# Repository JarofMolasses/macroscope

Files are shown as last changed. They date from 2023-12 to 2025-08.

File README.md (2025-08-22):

# Macroscope
This is a basic, constant-height, contact mode profilometer/AFM. It's really more of a demonstration piece but ~10 micron resolution can be achieved with some patience.

Inspired by this paper: [*Macro-scale atomic force microscope: An experimental platform for teaching precision mechatronics*](https://www.sciencedirect.com/science/article/abs/pii/S0957415815001488).

# Results
### Canadian nickel scanned at 1.75mm/s, 0.25mm resolution, 88x88 pixels 
A "quick" scan. It took 46 minutes.


### 3D printed test sample with 0.1mm steps. Scanned at 0.5mm/s, 0.05mm resolution, 60x20 pixels
You can see the diagonal print lines on the lowest step.


With a dollar for scale:



# Mechanical
## Initial working prototype 

## Second prototype 


# Control
This machine is programmed using SCPI-ish ASCII commands over a serial port.\
The control GUI we used for the prototype machines can be found here: https://github.com/JarofMolasses/macroscope_control. 

*Created by [David Antoniuk](https://github.com/DavidAntoniuk) and [myself](https://github.com/JarofMolasses).*

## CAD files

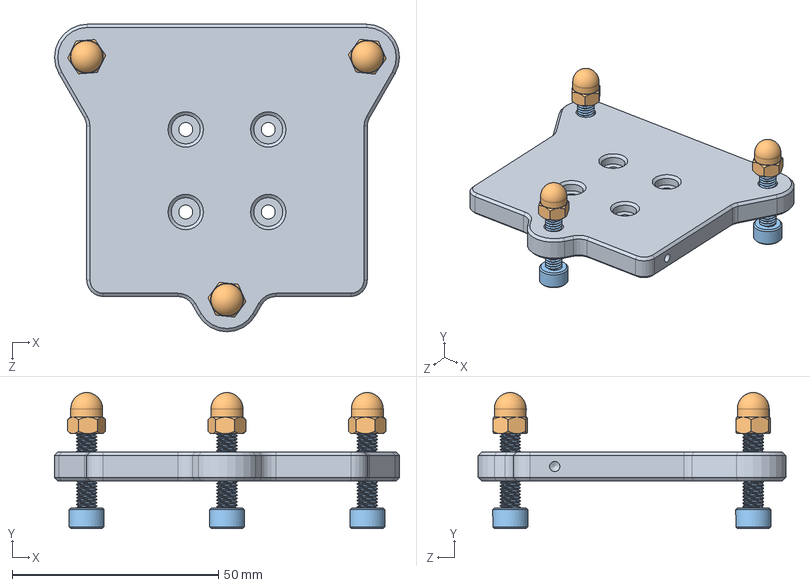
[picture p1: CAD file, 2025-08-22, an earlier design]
CAD archive/Kinematic_Mount_Subassembly.SLDASM
83.6 x 33.0 x 74.5 mm
Kinematic_Mount_Base
M5 94000A037_18-8 Stainless Steel Cap Nut x 3
M5x20 SHCS - 91292A128_18-8 Stainless Steel Socket Head Screw x 3

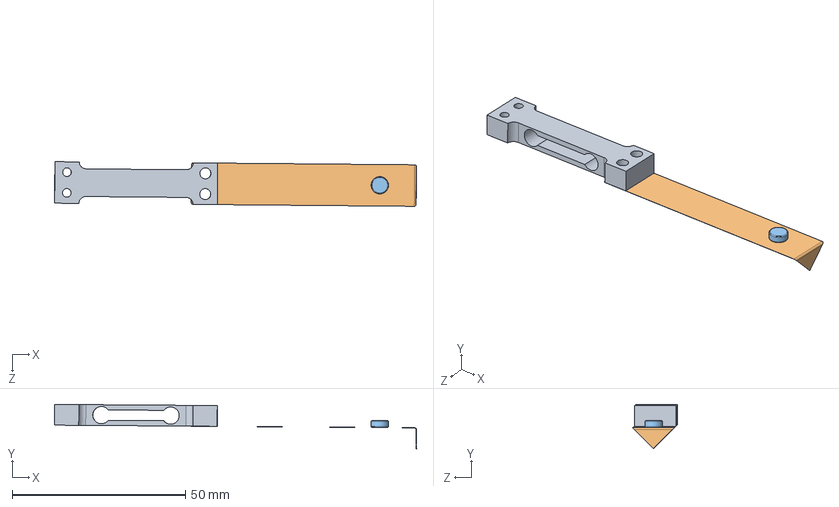
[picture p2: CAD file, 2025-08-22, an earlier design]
CAD archive/Probe_Subassembly.SLDASM
104.6 x 12.8 x 12.9 mm
Load_Cell
Probe
Magnet

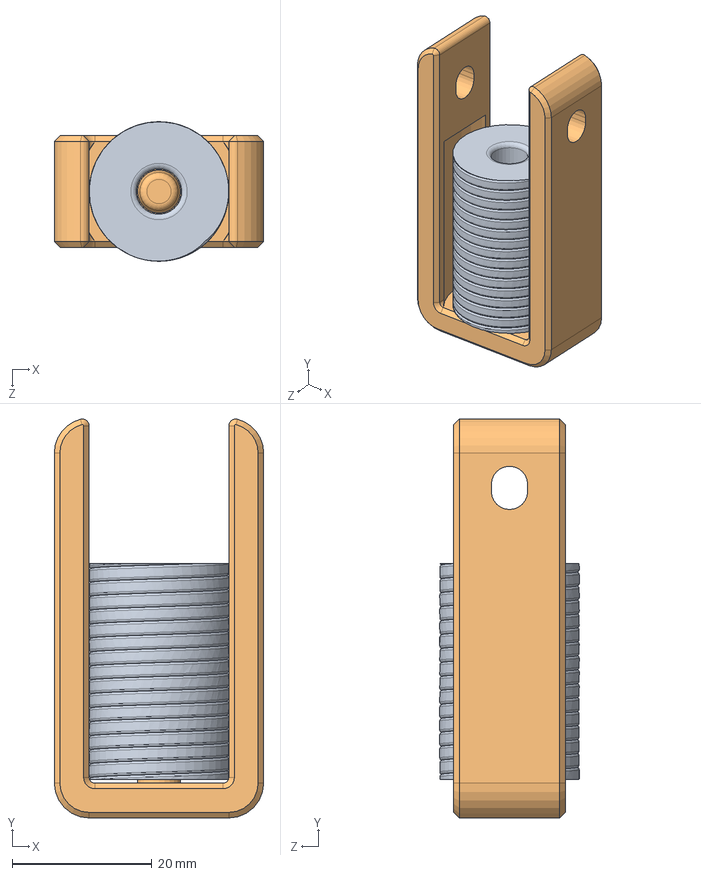
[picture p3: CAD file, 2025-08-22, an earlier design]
CAD archive/Coil_Subassembly.SLDASM
30.0 x 57.2 x 20.0 mm
Coil_Placeholder
Coil_Mount

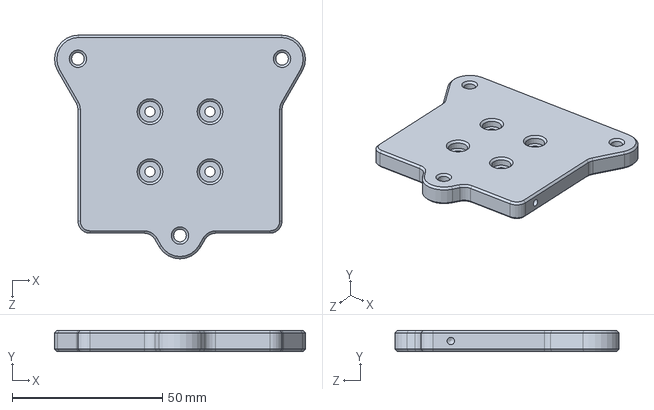
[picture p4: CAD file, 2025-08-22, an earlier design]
CAD archive/Kinematic_Mount_Base.SLDPRT
83.6 x 7.00 x 74.5 mm

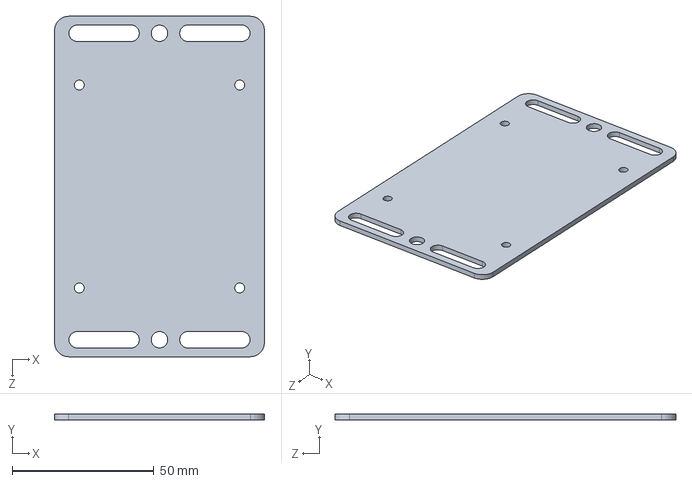
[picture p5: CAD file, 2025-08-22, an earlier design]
CAD archive/ADC backplate.SLDPRT
74.0 x 2.00 x 120.0 mm

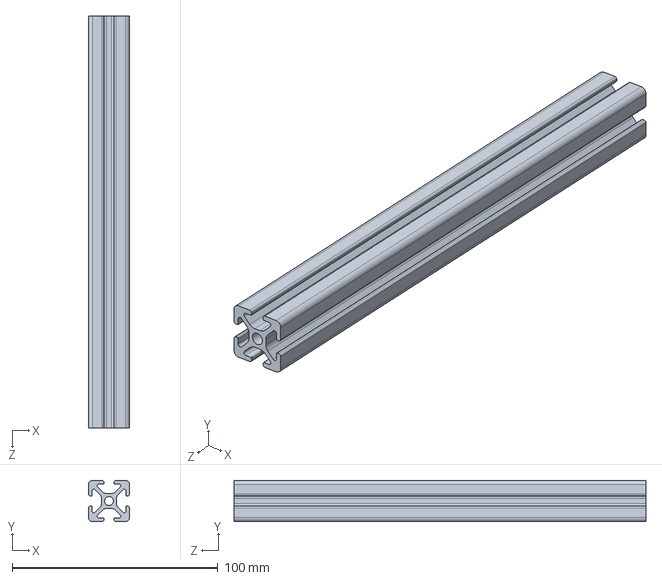
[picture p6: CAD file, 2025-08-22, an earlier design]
CAD archive/Extrusion_2020_200.SLDPRT
20.0 x 20.0 x 200.0 mm

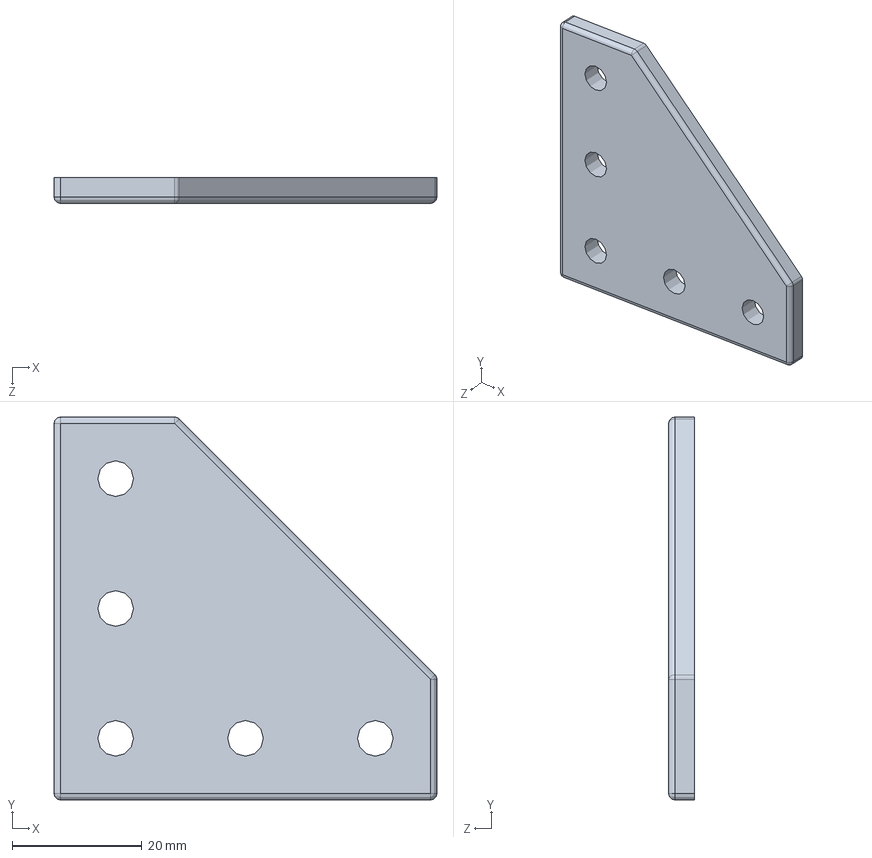
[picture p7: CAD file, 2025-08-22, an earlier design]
CAD archive/Corner_Bracket_5537T962.SLDPRT
59.0 x 59.0 x 4.00 mm

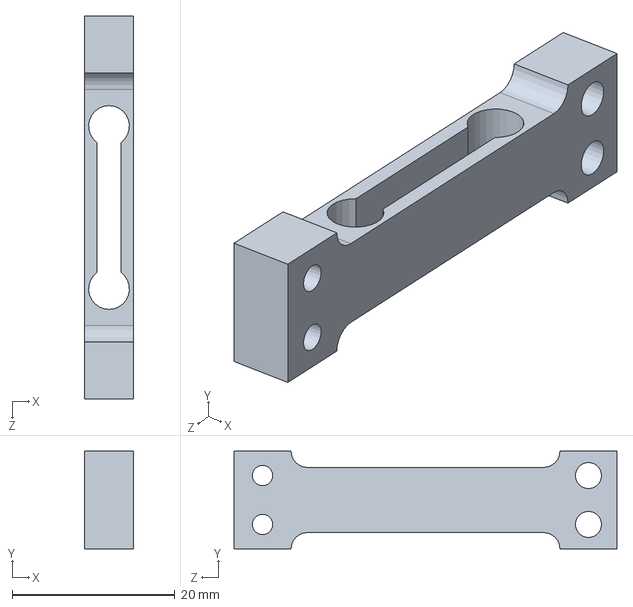
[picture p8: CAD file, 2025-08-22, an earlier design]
CAD archive/Load_Cell.SLDPRT
6.00 x 12.0 x 47.0 mm

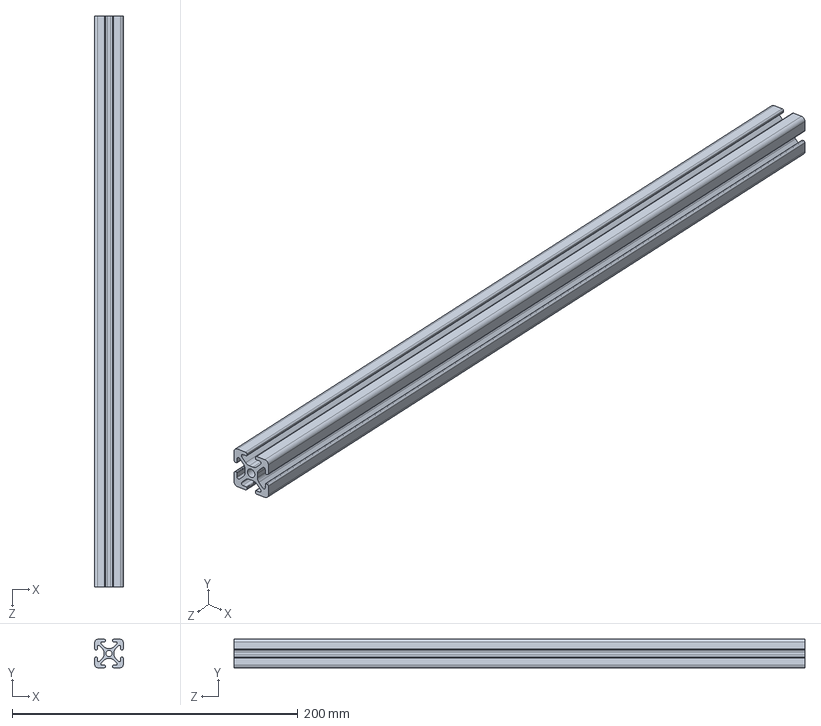
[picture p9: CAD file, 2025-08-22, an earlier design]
CAD archive/Extrusion_2020_400.SLDPRT
20.0 x 20.0 x 400.0 mm

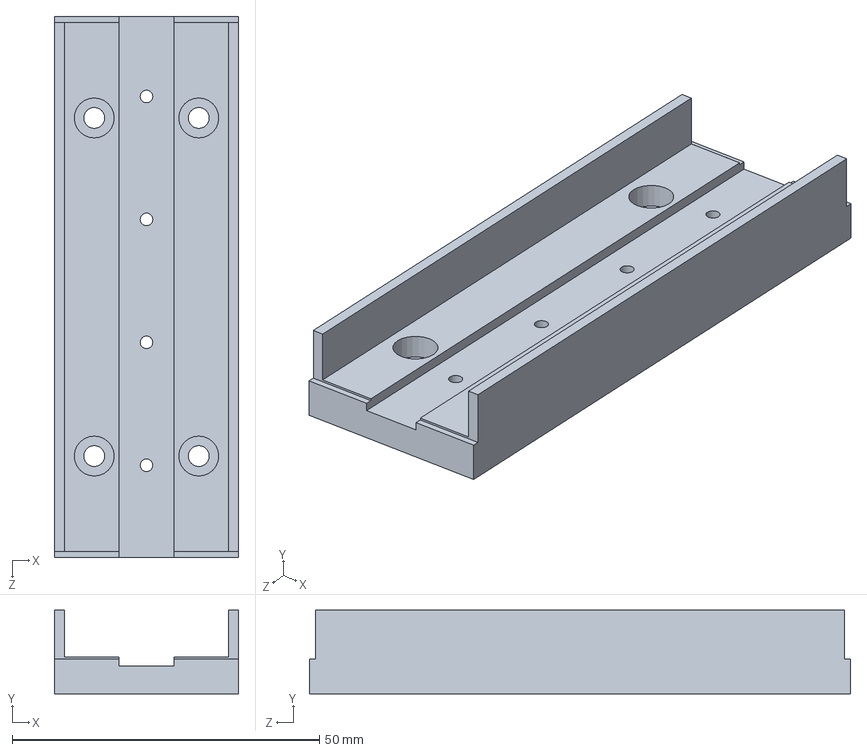
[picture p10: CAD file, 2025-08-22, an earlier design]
CAD archive/Base.SLDPRT
30.0 x 13.6 x 88.0 mm

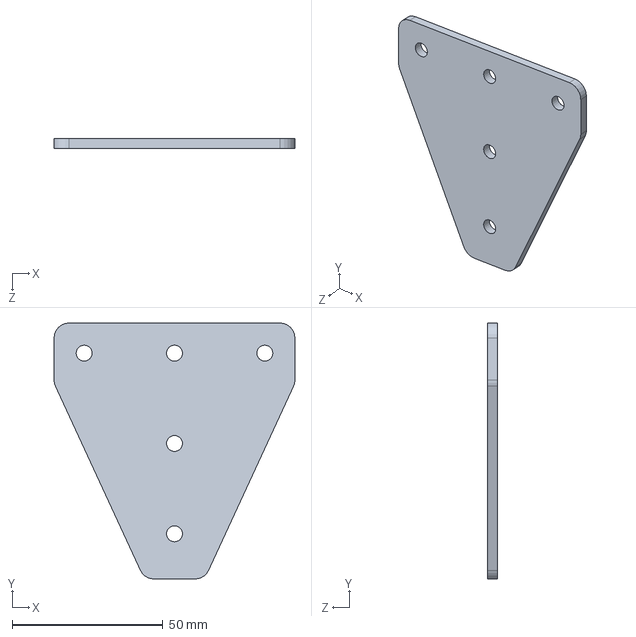
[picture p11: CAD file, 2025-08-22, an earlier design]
CAD archive/Vertical Brace.SLDPRT
80.0 x 85.0 x 3.17 mm

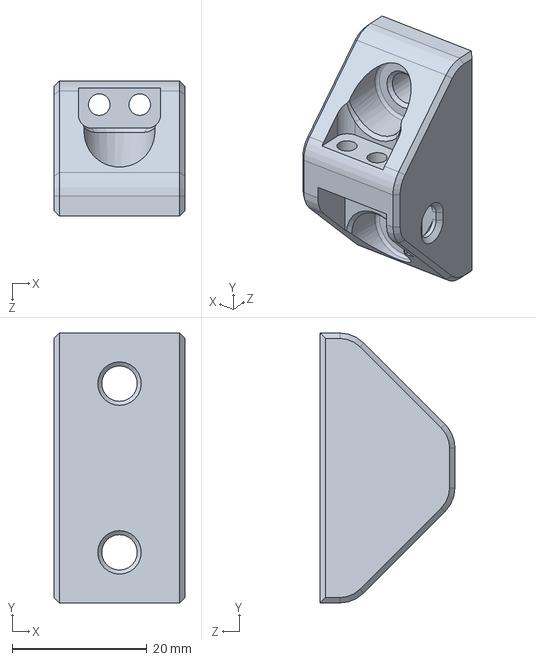
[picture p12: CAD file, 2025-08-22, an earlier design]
CAD archive/Load_Cell_Mounting_Block.SLDPRT
19.4 x 40.0 x 20.0 mm

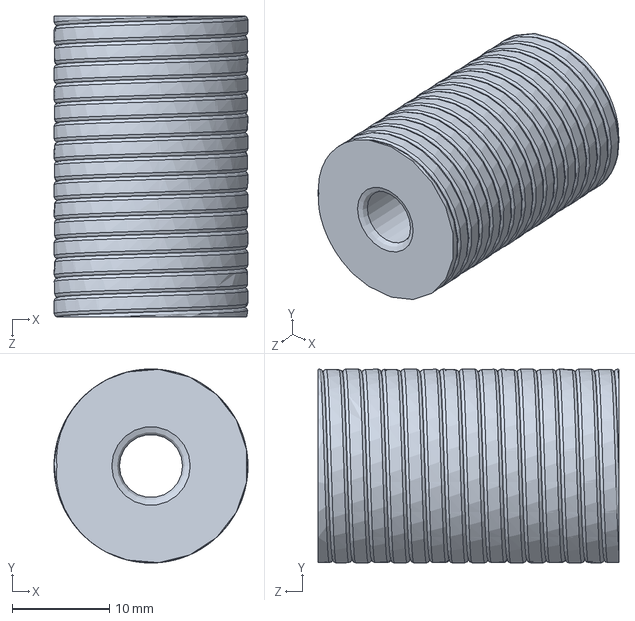
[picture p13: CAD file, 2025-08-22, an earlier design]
CAD archive/Coil_Placeholder.SLDPRT
20.0 x 20.0 x 31.0 mm

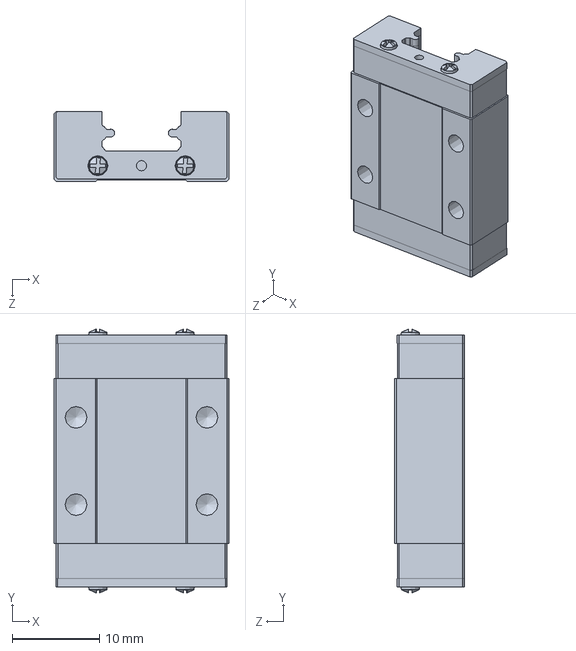
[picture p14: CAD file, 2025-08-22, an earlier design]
CAD archive/Actuator_MGN9C.SLDPRT
20.0 x 30.3 x 8.00 mm

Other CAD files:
CAD archive/Actuator_movable.SLDASM
CAD archive/Probe.SLDPRT
CAD archive/Corner_Bracket_423.SLDPRT
CAD archive/Wall_Back.SLDPRT
CAD archive/00144585.SLDASM
CAD archive/00144585_01.SLDPRT
CAD archive/00144585_02.SLDPRT
CAD archive/00144585_03.SLDPRT
CAD archive/00144585_04.SLDPRT
CAD archive/00144585_05.SLDPRT
CAD archive/00144585_06.SLDPRT
CAD archive/00144585_07.SLDPRT
CAD archive/00144585_08.SLDPRT
CAD archive/00144585_09.SLDPRT
CAD archive/00144585_10.SLDPRT
CAD archive/00144585_11.SLDPRT
CAD archive/00144585_12.SLDPRT
CAD archive/00144585_13.SLDPRT
CAD archive/00144585_14.SLDPRT
CAD archive/Actuator_MGN9.SLDPRT
CAD archive/Ballscrew.SLDPRT
CAD archive/Ballscrew_End_Large.SLDPRT
CAD archive/Ballscrew_End_Small.SLDPRT
CAD archive/Ballscrew_Extrusion.SLDPRT
CAD archive/Ballscrew_Motor_Coupling.SLDPRT
CAD archive/Ballscrew_Slider.SLDPRT
CAD archive/Ballscrew_Stopper.SLDPRT
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

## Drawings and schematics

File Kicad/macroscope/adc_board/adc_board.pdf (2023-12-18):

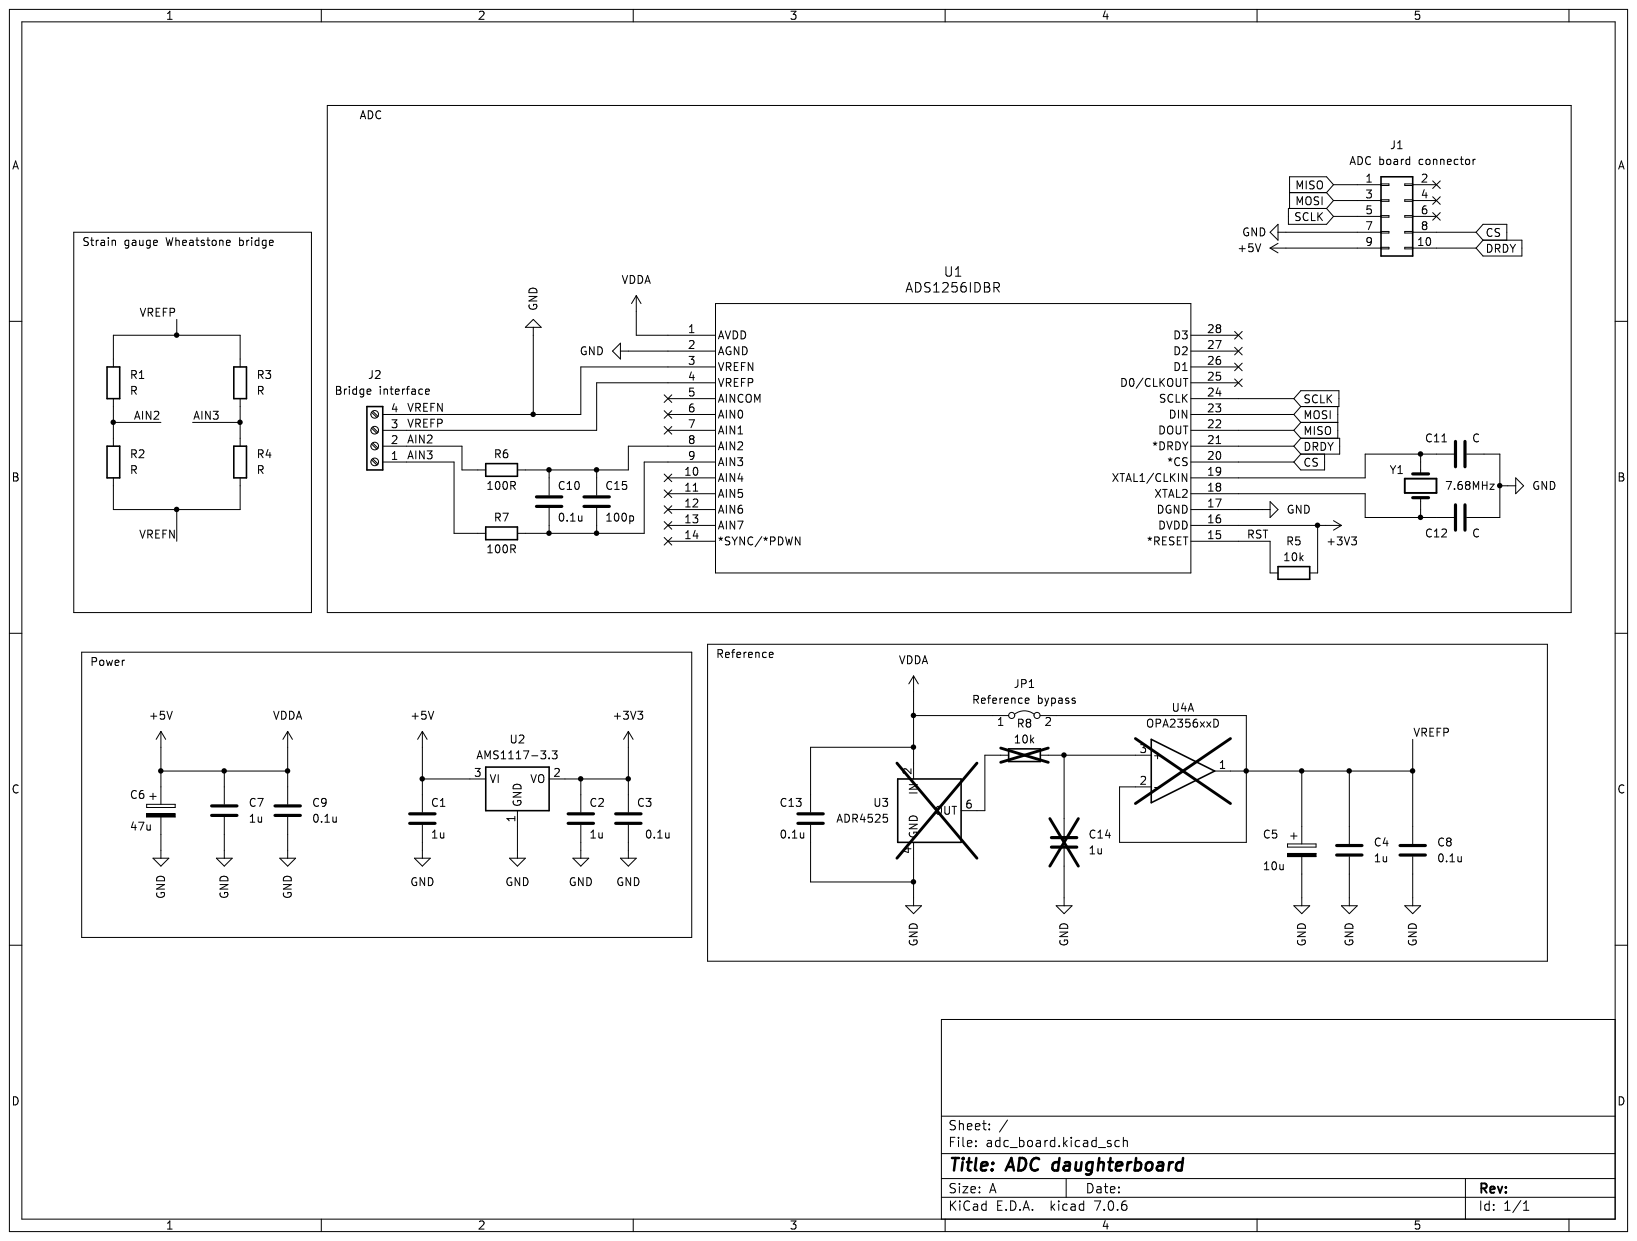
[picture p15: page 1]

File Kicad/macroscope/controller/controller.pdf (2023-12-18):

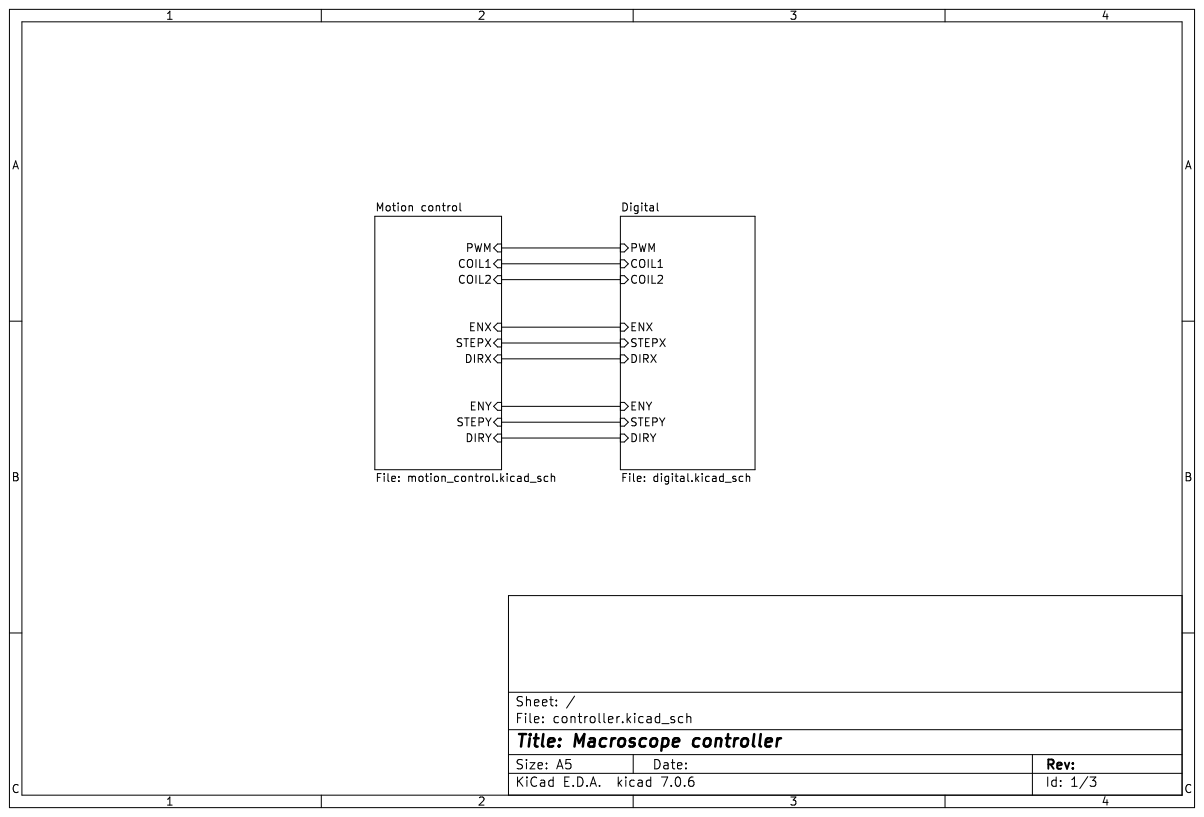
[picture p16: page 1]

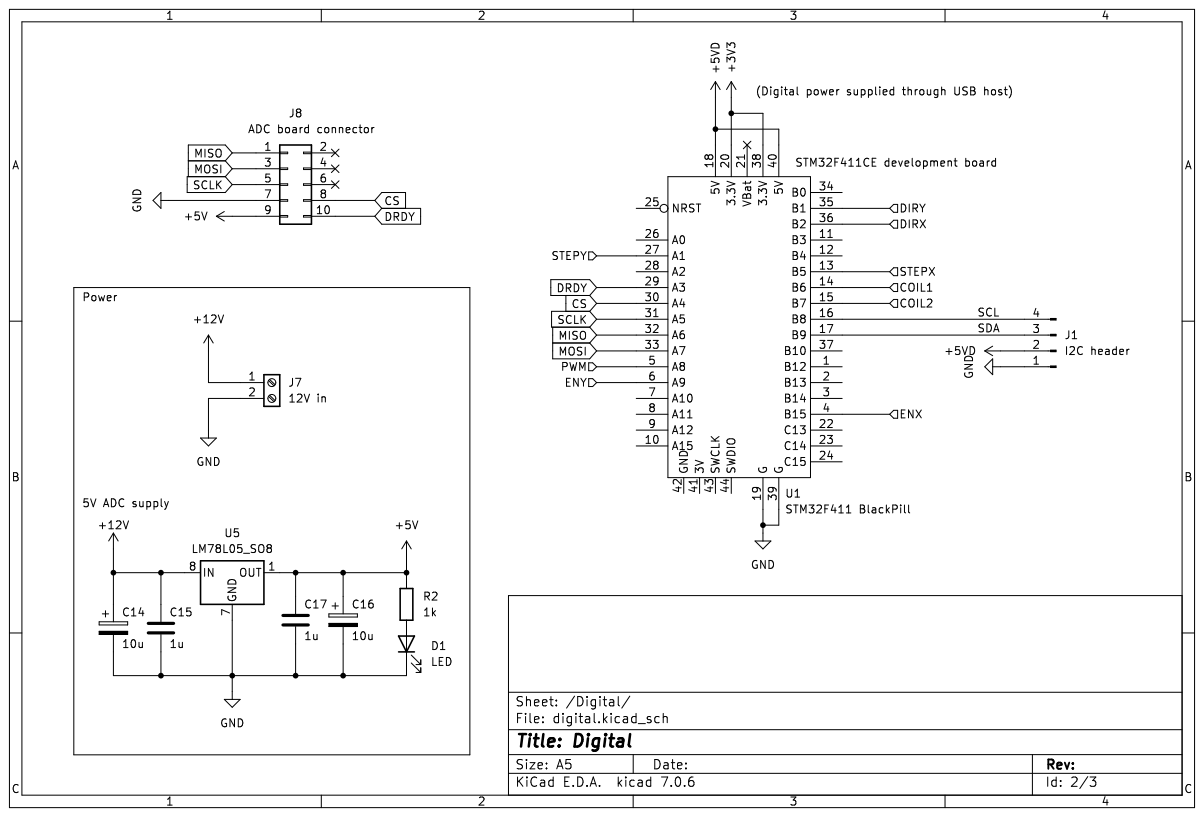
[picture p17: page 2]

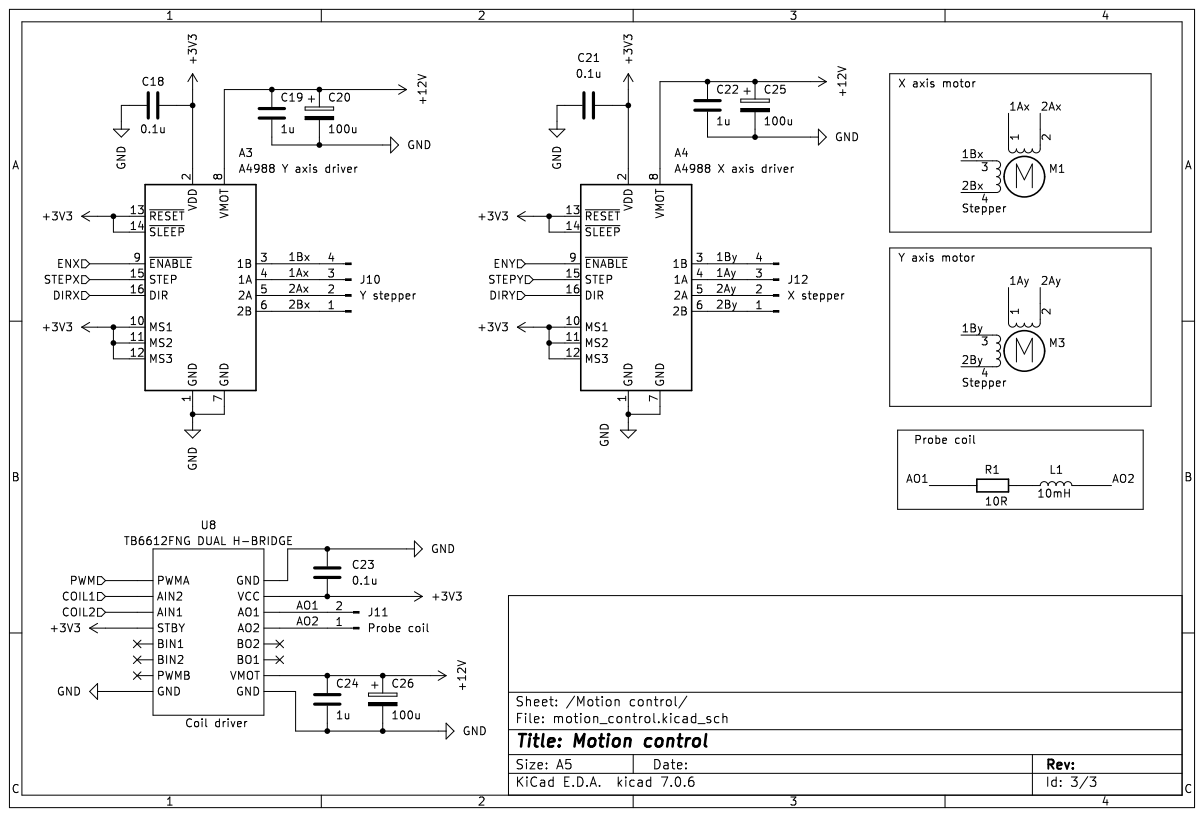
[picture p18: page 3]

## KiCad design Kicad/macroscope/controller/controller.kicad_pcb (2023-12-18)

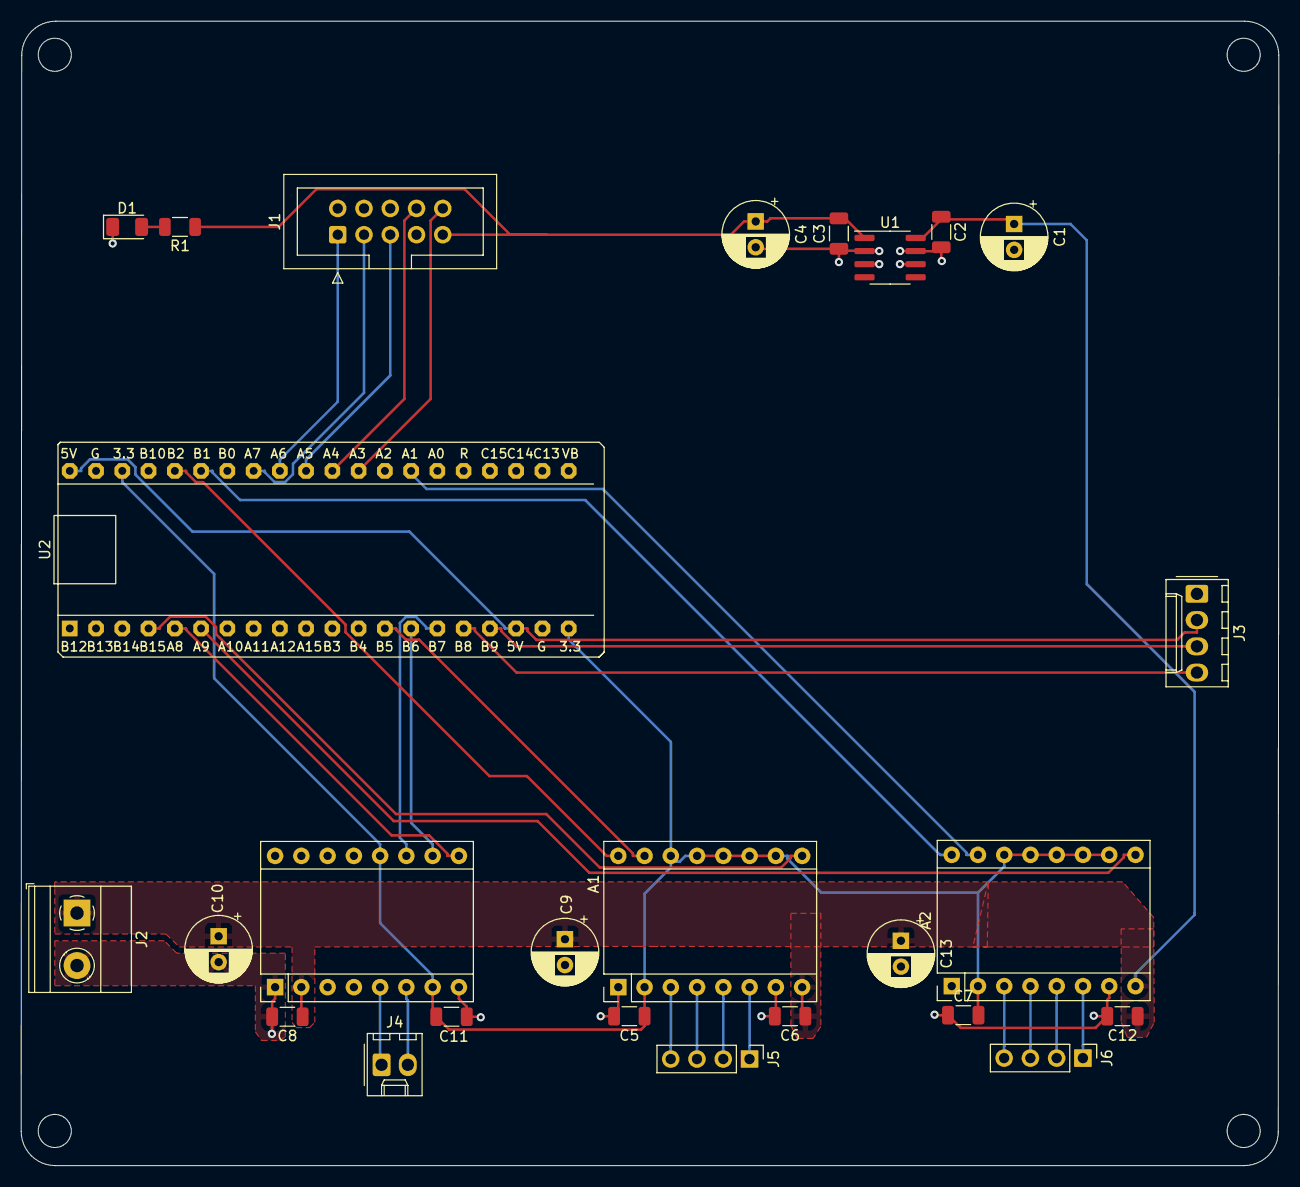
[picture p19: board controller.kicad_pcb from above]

Board: 2 copper layers, 121.7 x 110.7 mm, 30 parts (0 on the bottom side), 32 nets.

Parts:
A1: A4988 Y axis driver; A4988_Pololu_Breakout-16_15.2x20.3mm
A2: A4988 X axis driver; A4988_Pololu_Breakout-16_15.2x20.3mm
C1, C4: 10u; CP_Radial_D6.3mm_P2.50mm
C2, C3, C6, C8, C12: 1u; C_1206_3216Metric
C5, C7, C11: 0.1u; C_1206_3216Metric
C9, C10, C13: 100u; CP_Radial_D6.3mm_P2.50mm
D1: LED; LED_1206_3216Metric
H1, H2, H3, H4: MountingHole; MountingHole_3.2mm_M3_ISO7380
J1: ADC board connector; IDC-Header_2x05_P2.54mm_Vertical
J2: 12V in; TerminalBlock_Phoenix_MKDS-1,5-2-5.08_1x02_P5.08mm_Horizont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
J3: I2C header; Molex_KK-254_AE-6410-04A_1x04_P2.54mm_Vertical
J4: Probe coil; Molex_KK-254_AE-6410-02A_1x02_P2.54mm_Vertical
J5: Y stepper; PinHeader_1x04_P2.54mm_Vertical
J6: X stepper; PinHeader_1x04_P2.54mm_Vertical
R1: 1k; R_1206_3216Metric
U1: LM78L05_SO8; SOIC-8_3.9x4.9mm_P1.27mm
U2: STM32F411 BlackPill; STM32F411_Black_Pill
U3: Coil driver; TB6612FNG_Pololu_Breakout-16_15.2x20.3mm

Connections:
+3V3: A1.2 (VDD), A1.10 (MS1), A1.11 (MS2), A1.12 (MS3), A1.13 (~RESET), A1.14 (~SLEEP), A2.2 (VDD), A2.10 (MS1), A2.11 (MS2), A2.12 (MS3), A2.13 (~RESET), A2.14 (~SLEEP), C5.1, C7.2, C11.1, U2.20 (3.3V), U2.38 (3.3V), U3.7 (VCC), U3.12 (STBY)
+5V: C3.1, C4.1, J1.9, R1.1, U1.1 (OUT)
+5VD: J3.2, U2.18 (5V), U2.40 (5V)
+12V: A1.8 (VMOT), A2.8 (VMOT), C1.1, C2.1, C6.1, C8.1, C9.1, C10.1, C12.1, C13.1, J2.1, U1.8 (IN), U3.2 (VMOT)
/Digital/COIL1: U2.14 (B6), U3.10 (AIN2)
/Digital/COIL2: U2.15 (B7), U3.11 (AIN1)
/Digital/DIRX: A1.16 (DIR), U2.36 (B2)
/Digital/DIRY: A2.16 (DIR), U2.35 (B1)
/Digital/ENX: A1.9 (~ENABLE), U2.4 (B15)
/Digital/ENY: A2.9 (~ENABLE), U2.6 (A9)
/Digital/PWM: U2.5 (A8), U3.9 (PWMA)
/Digital/SCL: J3.4, U2.16 (B8)
/Digital/SDA: J3.3, U2.17 (B9)
/Digital/STEPX: A1.15 (STEP), U2.13 (B5)
/Digital/STEPY: A2.15 (STEP), U2.27 (A1)
/Motion control/1Ax: A1.4 (1A), J5.3
/Motion control/1Ay: A2.4 (1A), J6.3
/Motion control/1Bx: A1.3 (1B), J5.4
/Motion control/1By: A2.3 (1B), J6.4
/Motion control/2Ax: A1.5 (2A), J5.2
/Motion control/2Ay: A2.5 (2A), J6.2
/Motion control/2Bx: A1.6 (2B), J5.1
/Motion control/2By: A2.6 (2B), J6.1
/Motion control/AO1: J4.2, U3.6 (AO1)
/Motion control/AO2: J4.1, U3.5 (AO2)
CS: J1.8, U2.30 (A4)
DRDY: J1.10, U2.29 (A3)
GND: A1.1 (GND), A1.7 (GND), A2.1 (GND), A2.7 (GND), C1.2, C2.2, C3.2, C4.2, C5.2, C6.2, C7.1, C8.2, C9.2, C10.2, C11.2, C12.2, C13.2, D1.1 (K), J1.7, J2.2, J3.1, U1.2 (GND), U1.3 (GND), U1.6 (GND), U1.7 (GND), U2.19 (G), U2.39 (G), U3.1 (GND), U3.8 (GND), U3.16 (GND)
MISO: J1.1, U2.32 (A6)
MOSI: J1.3, U2.33 (A7)
unnamed: D1.2 (A), R1.2
SCLK: J1.5, U2.31 (A5)

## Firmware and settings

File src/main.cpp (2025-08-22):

/** Project: Atomic force macroscope
 * 
 * Board: Blackpill V2.0 STM32F411CEU6
 * Clock: 84MHz
 * 
 * See config.h for wiring scheme
 * 
 */

/**TIMER ALLOCATIONS:
 * TIM9 - main timer system event timer internal 
 *  CH1: UART
 *  CH2: LCD
 * 
 * TIM11 - secondary timer internal (unused)
 *  
 * TIM4 
 *  Ch1 - PB6 - coil PWMA     
 *  Ch2 - PB7 - coil PWMB
 * TIM1
 *  Ch1 - Aux PWM signal. 
 * 
 * TIM3 Ch2 - PB5 - X stepper pulse generator 
 * TIM2 Ch2 - PA1 - Y stepper pulse generator
 * What if you want a third stepper? 
 * TIM5 can be accessed as a secondary option on PA0
 * TIM4 can be freed up if we don't need the coast mode for the coil driver
 * TIM10 is hard to get at, only one pin carries it and it's not convenient
*/
#define LCD_LENGTH 20
#define ADC_BUFFER_SIZE 10

#include <HardwareTimer.h>
#include <SPI.h>
#include <Wire.h>
#include "AsyncStepper.h"
#include "ADS1256.h"
#include "config.h"
#include "liquidcrystal_i2c.h"
#include "Vrekrer_scpi_parser.h"
#include <queue>

/**
 * A silly debug LCD. 20x4 characters
*/
char lcdline0[LCD_LENGTH+1];
char lcdline1[LCD_LENGTH+1];
char lcdline2[LCD_LENGTH+1];
char lcdline3[LCD_LENGTH+1];

/* uart print buffer */
char uartBuffer[48];
char checksumBuffer[8];

/**
 * ADC components
*/
ADS1256 adc(ADC_DRDY, 0, ADC_SYNC, ADC_CS, 5.00);    
int32_t adcRawCounts = 0;
double adcVolts = 0;
double adcForce = 0;
double adcHeight = 0;
/**
 * Calibration constants
 * Force in cN
 * Distance in mm
*/
double counts_to_cN = 0.03;
double counts_offset = 0.00;
double force_to_mm = (1.0/19600)*1000;  // 19600 cN/m
/**
 * Amplitude measurement buffer
*/
std::queue<int32_t> adcBuffer;



/* Step pulse generators */
/**
 * Currently selects T3Ch2 and T2Ch2 automatically for X and Y steppers.
*/
TIM_TypeDef *Instance_x = (TIM_TypeDef *)pinmap_peripheral(digitalPinToPinName(stepPinx), PinMap_PWM);
uint32_t PWMchannel_x = STM_PIN_CHANNEL(pinmap_function(digitalPinToPinName(stepPinx), PinMap_PWM));
HardwareTimer *Timer_x = new HardwareTimer(Instance_x);
TIM_TypeDef *Instance_y = (TIM_TypeDef *)pinmap_peripheral(digitalPinToPinName(stepPiny), PinMap_PWM);
uint32_t PWMchannel_y = STM_PIN_CHANNEL(pinmap_function(digitalPinToPinName(stepPiny), PinMap_PWM));
HardwareTimer *Timer_y = new HardwareTimer(Instance_y);
AsyncStepper xStepper = AsyncStepper(stepPinx, dirPinx, enPinx, Timer_x, PWMchannel_x, 40000);
AsyncStepper yStepper = AsyncStepper(stepPiny, dirPiny, enPiny, Timer_y, PWMchannel_y, 40000);

/**
 * Coil driver components
 */     
HardwareTimer *coilPWMTimer = new HardwareTimer(TIM4);
HardwareTimer *auxPWMTimer = new HardwareTimer(TIM1);
uint8_t PWMchannel_coilA = 1;     // Check datasheet and pinout to find the right channel
uint8_t PWMchannel_coilB = 2;
uint8_t PWMchannel_coil = 1;
volatile uint32_t probeFrequency = 36;      
volatile uint32_t coilPWMFrequency = probeFrequency*2 * SINETABLESIZE*2;
volatile uint8_t coilSineDegrees = 0;   // Tracks the degree step through the sine table
// volatile uint8_t coilDutyCycle = 0;     // Current required duty cycle converted from sine table
volatile bool coilState = false;        // Tracks which coil input is active
volatile sineModes_T sineMode = SQUARE;  // Tracks TB6612 driving mode

/* Square/ brake mode specifics*/
volatile uint8_t auxDutyCycle = 30;      // aux (supply-side) PWM duty cycle for square wave drive
volatile uint8_t staticDutyCycle = 70;   // static duty cycle has to be higher to get appreciable tip deflection
volatile uint16_t sineTableOverflow = 0;          // To set peak voltage of sine wave from auxDutyCycle
volatile uint16_t sineTableDutyCycleFactor = 1;   // To set peak voltage of sine wave from auxDutyCycle


/**
 * System timers
 */           
HardwareTimer *mainTimer = new HardwareTimer(TIM9);      // HardwareTimer makes some configs convenient. low-level registers accessible through TIMx
HardwareTimer *tim11 = new HardwareTimer(TIM11);           // Convenient aux timer handle via HardwareTimer 
volatile uint16_t uartFreq = 50;
volatile uint16_t lcdFreq = 1;
volatile uint16_t uartTicks = 0;
volatile uint16_t lcdTicks = 0;
volatile bool ledOn = false;                          // UART debug LED
volatile bool executeStepFlag = false;
volatile bool lcdFlag = false;
volatile bool logOn = false;
volatile uint32_t rasterLines = 0;

SCPI_Parser parser;

/**
 * return: measured force in centinewtons
*/
double countsToCN(int32_t counts)
{
  return (counts - counts_offset)* counts_to_cN;
}
/**
 * return: measured displacement in millimeters
*/
double cNtoMillimeters(double cN)
{
  return cN*force_to_mm;
}
void adcUpdateAll()
{
  adcRawCounts = adc.readSingle();
  adcBuffer.push(adcRawCounts);
  if(adcBuffer.size() >= ADC_BUFFER_SIZE)
  {
    adcBuffer.pop();
  }
  adcVolts = adc.convertToVoltage(adcRawCounts);
  adcForce = countsToCN(adcRawCounts);
  adcHeight = cNtoMillimeters(adcForce);
}

void updateLCD(byte l1, byte l2, byte l3, byte l4)
{
  if(l1){
  snprintf(lcdline0, LCD_LENGTH+1, "ADC : %+0.8f mm",adcHeight);
  HD44780_SetCursor(0,0);
  HD44780_PrintStr(lcdline0);
  }
  if(l2){
  snprintf(lcdline1, LCD_LENGTH+1, "  X:%-6d Y:%-6d",xStepper.currentPosition(), yStepper.currentPosition());
  HD44780_SetCursor(0,1);
  HD44780_PrintStr(lcdline1);
  }
  if(l3){
  snprintf(lcdline2, LCD_LENGTH+1, "COIL: %-4d Hz",probeFrequency);
  HD44780_SetCursor(0,2);
  HD44780_PrintStr(lcdline2);
  }
  if(l4){
  snprintf(lcdline3, LCD_LENGTH+1, "UART: %9d Hz",uartFreq);
  HD44780_SetCursor(0,3);
  HD44780_PrintStr(lcdline3);
  }
}

/**
 * Main system timer ISR
*/
void timer9_1ISR()
{
  if(logOn)
  {
    ledOn = !ledOn;     
    digitalWrite(PC13, ledOn ? HIGH:LOW);
    // Byte packet version
    // uint8_t adcHighByte = (uint8_t)adcRawCounts>>16;
    // uint8_t adcMidByte = (uint8_t)adcRawCounts>>8;
    // uint8_t adcLowByte = (uint8_t)adcRawCounts;
    // uint8_t xHighByte = (uint8_t)xStepper.currentPosition()>>8;
    // uint8_t xLowByte = (uint8_t)xStepper.currentPosition();
    // uint8_t yHighByte = (uint8_t)yStepper.currentPosition()>>8;
    // uint8_t yLowByte = (uint8_t)yStepper.currentPosition();
    // uint8_t escape = 0;
    // Serial.write(0xFF);       // Start byte
    // Serial.write(adcHighByte);
    // Serial.write(adcMidByte);
    // Serial.write(adcLowByte);
    // Serial.write(xHighByte);
    // Serial.write(xLowByte);
    // Serial.write(yHighByte);
    // Serial.write(yLowByte);
    // Serial.write(escape);
    
    uint32_t checksum = sprintf(uartBuffer, "__DATA__,%d,%d,%d,", adcRawCounts, xStepper.currentPosition(), yStepper.currentPosition());
    sprintf(checksumBuffer, "%d", checksum);
    Serial.print(uartBuffer);
    Serial.println(checksum);
  }

  TIM9->CCR1 += uartTicks;
}
void timer9_2ISR()
{
  lcdFlag = true;   // Slow and unimportant, do it in the loop

  TIM9->CCR2 += lcdTicks;
}

/**
 * Secondary system timer ISR
*/
void timer11_0ISR()
{
  executeStepFlag = true;
  if(rasterLines++ == 100)
  {
        xStepper.runSpeedToPosition(xStepper.currentPosition()+100);
        rasterLines = 0;
  }
  yStepper.runSpeedToPosition(yStepper.currentPosition()+100);
  executeStepFlag = false;
}


/**
 * Coil ISR for run/brake PWM using PWM pin
*/
void coilBrakeISR()
{
  if(coilSineDegrees == (SINETABLESIZE*2-1))
  {
    coilSineDegrees = 0;
    coilState = !coilState;
    digitalWriteFast(digitalPinToPinName(coilInA), coilState? HIGH:LOW);
    digitalWriteFast(digitalPinToPinName(coilInB), coilState? LOW:HIGH);
  }

  switch(sineMode)
  {
    case BRAKE:   // Produce sine function from lookup table on PWM pin
    {
      uint16_t compactSineIndex = coilSineDegrees<=(SINETABLESIZE)?coilSineDegrees : SINETABLESIZE-coilSineDegrees%SINETABLESIZE;  // Take only the wraparound value
      
      // uint16_t overflow = auxPWMTimer->getOverflow(TICK_FORMAT);
      // uint16_t sin = (overflow/255)*pgm_read_byte(&sinA[compactSineIndex]);

      uint16_t sin = (sineTableDutyCycleFactor)*pgm_read_byte(&sinA[compactSineIndex]);
      auxPWMTimer->setCaptureCompare(PWMchannel_coil, sin, TICK_COMPARE_FORMAT); // update sine duty cycle on PWM pin
    }
    break;
    case SQUARE:   // Just use the default constant PWM duty cycle
    break;
    default:
    break;
  }
  coilSineDegrees = (coilSineDegrees+1) % (SINETABLESIZE*2);    // update coil degrees, SINETABLE is only 90 degrees. 2 for a full 180
}

/**
 * Coil ISR for run/coast PWM using IN pins
*/
void coilCoastISR()
{
  if(coilSineDegrees == (SINETABLESIZE*2)-1)
  {
    coilSineDegrees = 0;    
    coilState = !coilState;

    // temporary: for hardware debug.
    digitalWrite(PB13, coilState?HIGH:LOW);
  }
  uint16_t compactSineIndex = coilSineDegrees<=(SINETABLESIZE)?coilSineDegrees : SINETABLESIZE-coilSineDegrees%SINETABLESIZE;  // Take only the wraparound value
  
  // This is slow. You can calculate constants at the first call 
  uint16_t overflow = coilPWMTimer->getOverflow(TICK_FORMAT);
  uint16_t sin = (overflow/255)*pgm_read_byte(&sinA[compactSineIndex]);

  if(coilState)
  {
    coilPWMTimer->setCaptureCompare(PWMchannel_coilA, sin, TICK_COMPARE_FORMAT); // update sine duty cycle on PWM pin
    coilPWMTimer->setCaptureCompare(PWMchannel_coilB, 0, PERCENT_COMPARE_FORMAT);
  }
  else
  {
    coilPWMTimer->setCaptureCompare(PWMchannel_coilB, sin, TICK_COMPARE_FORMAT); 
    coilPWMTimer->setCaptureCompare(PWMchannel_coilA, 0, PERCENT_COMPARE_FORMAT);
  }
  coilSineDegrees = (coilSineDegrees+1) % (SINETABLESIZE*2);    // update coil degrees, SINETABLE is only 90 degrees. 2 for a full 180
}

void stopCoil()
{   
  coilPWMTimer->detachInterrupt();
  switch(sineMode)
  {
    case COAST:
      coilPWMTimer->setCaptureCompare(PWMchannel_coilA, 0, PERCENT_COMPARE_FORMAT);
      coilPWMTimer->setCaptureCompare(PWMchannel_coilB, 0, PERCENT_COMPARE_FORMAT);
      coilPWMTimer->refresh();
      coilPWMTimer->pause();   
    break;
    case BRAKE:
    case SQUARE:                      // Square wave and brake mode share the same ISR and setup
      auxPWMTimer->detachInterrupt();
      auxPWMTimer->setCaptureCompare(PWMchannel_coil, 0, PERCENT_COMPARE_FORMAT);
      auxPWMTimer->refresh();
      auxPWMTimer->pause();
    break;
    default:
    break;
  }      

  /* Return coil driver inputs plain GPIO outputs */
  pinMode(coilInA,OUTPUT);
  pinMode(coilInB,OUTPUT);     
  digitalWrite(coilInA, LOW);
  digitalWrite(coilInB, LOW);                                    
}

void startCoil()
{
  switch(sineMode)
  {
    case COAST:
      coilPWMTimer->setPWM(PWMchannel_coilA, coilInA, coilPWMFrequency, 0);
      coilPWMTimer->setPWM(PWMchannel_coilB, coilInB, coilPWMFrequency, 0);
      coilState = false;
      coilSineDegrees = 0;
      coilPWMTimer->attachInterrupt(coilCoastISR);
      coilPWMTimer->refresh();
      coilPWMTimer->resume(); 
      break;
    case BRAKE:
    case SQUARE:                     // Square wave and brake mode share the same ISR and setup
      pinMode(coilInA,OUTPUT);
      pinMode(coilInB,OUTPUT);
      auxPWMTimer->setPWM(PWMchannel_coil, coilPWMPinAux, coilPWMFrequency, auxDutyCycle);
      coilState = false;
      coilSineDegrees = 0;
      auxPWMTimer->attachInterrupt(coilBrakeISR);
      auxPWMTimer->refresh();
      auxPWMTimer->resume(); 

      sineTableOverflow = auxPWMTimer->getOverflow(TICK_FORMAT);      // update constants for ISR calculations
      sineTableDutyCycleFactor = (uint16_t) (auxDutyCycle/100.0 * sineTableOverflow/255);
      break;
    default:
      break;
  }
}

void liftCoil()
{
  startCoil();
  stopCoil();
  digitalWrite(coilInA, HIGH);
  digitalWrite(coilInB, LOW);
  auxPWMTimer->setCaptureCompare(PWMchannel_coil, staticDutyCycle, PERCENT_COMPARE_FORMAT);
  auxPWMTimer->refresh();
  auxPWMTimer->resume();
}

void dropCoil()
{
  startCoil();
  stopCoil();
  digitalWrite(coilInA, LOW);
  digitalWrite(coilInB, HIGH);
  auxPWMTimer->setCaptureCompare(PWMchannel_coil, staticDutyCycle, PERCENT_COMPARE_FORMAT);
  auxPWMTimer->refresh();
  auxPWMTimer->resume();
}

/**
 * Reset ADC to default settings
*/
void resetADC()
{
  adc.sendDirectCommand(RESET);
  adc.setPGA(PGA_32);
  adc.setAutoCal(ACAL_DISABLED);
  adc.setDRATE(DRATE_60SPS);
  adc.setMUX(DIFF_2_3);
}

/**
 * Entry to the stepper step update ISRs
*/
void xStepISR()
{
  xStepper.stepTimerISR();    // use this ISR to enter the real ISR
}
void yStepISR()
{
  yStepper.stepTimerISR();
}

// ===================================SCPI COMMAND INTERMEDIATE FUNCTIONS - YOU SHOULD PUT BUSINESS LOGIC IN THEIR OWN FUNCTIONS=================================//

/* Execute local callback with specified number of parameters. signed int32 params only for now.*/
void scpi_nCallInt32(SCPI_P parameters, uint8_t size, void func_ptr(int32_t*), String message)
{
   if(parameters.Size()==size)    // TODO: check if numeric
  {
    int32_t target[size];
    for(int i = 0; i < size; i++)
    {
      target[i] = ((int32_t)String(parameters[i]).toInt());
    }
    (*func_ptr)(target);
    Serial.println(message);
  }
  else{
    Serial.println("Incorrect parameter length or format");
  }
}

/* Set UART transfer rate */
void scpi_uartDrate(SCPI_C commands, SCPI_P parameters, Stream& interface)
{
  uartFreq = String(parameters[0]).toInt();
  mainTimer->setOverflow(1,HERTZ_FORMAT);
  mainTimer->setCaptureCompare(1, uartFreq, HERTZ_COMPARE_FORMAT);
  uartTicks = mainTimer->getCaptureCompare(1);                      // Calculate number of ticks to increment and store in uartTicks 
}

/* Toggle UART logging */
void scpi_uartLog(SCPI_C commands, SCPI_P parameters, Stream& interface)
{
  logOn = (bool)String(parameters[0]).toInt();
}

void xySpeed(int32_t* speed)
{
  xStepper.setSpeed(speed[0]);
  yStepper.setSpeed(speed[1]);
  HD44780_SetCursor(0,3);
  snprintf(lcdline3, LCD_LENGTH+1, "SPD X%-6d Y%-6d", speed[0], speed[1]);
  HD44780_PrintStr(lcdline3);
}
void scpi_xySpeed(SCPI_C commands, SCPI_P parameters, Stream& interface)
{
  scpi_nCallInt32(parameters,2,xySpeed,"speed xy");
}

/* internal function x absolute*/
void xAbs(int32_t* pos)
{
  if(pos[0]>=0)
  {
  xStepper.runSpeedToPosition(pos[0]);
  HD44780_SetCursor(0,3);
  snprintf(lcdline3, LCD_LENGTH+1, "A X%-6d            ", pos[0]);
  HD44780_PrintStr(lcdline3);  
  }
}

/* Run X to absolute position */
void scpi_xAbs(SCPI_C commands, SCPI_P parameters, Stream& interface)
{
  scpi_nCallInt32(parameters,1,&xAbs,"move X absolute");
}

void xStep(int32_t *pos)
{
  int32_t stepX = pos[0];
  xStepper.runSpeedToPosition(xStepper.currentPosition()+stepX);
  HD44780_SetCursor(0,3);
  snprintf(lcdline3, LCD_LENGTH+1, "R X%-6d            ", stepX);
  HD44780_PrintStr(lcdline3);
}

void scpi_xStep(SCPI_C commands, SCPI_P parameters, Stream& interface)
{
  scpi_nCallInt32(parameters,1,&xStep, "move X relative");
}

/* internal function y absolute*/
void yAbs(int32_t* pos)
{
  if(pos[0]>=0)
  {
    yStepper.runSpeedToPosition(pos[0]);
    HD44780_SetCursor(0,3);
    snprintf(lcdline3, LCD_LENGTH+1, "A Y%-6d            ", pos[0]);
    HD44780_PrintStr(lcdline3);
  }
}

void scpi_yAbs(SCPI_C commands, SCPI_P parameters, Stream& interface)
{
  scpi_nCallInt32(parameters,1,&yAbs,"move Y absolute");
}

void yStep(int32_t *pos)
{
  int32_t stepY = pos[0];
  yStepper.runSpeedToPosition(yStepper.currentPosition()+stepY);
  HD44780_SetCursor(0,3);
  snprintf(lcdline3, LCD_LENGTH+1, "R Y%-6d            ", stepY);
  HD44780_PrintStr(lcdline3);
}

void scpi_yStep(SCPI_C commands, SCPI_P parameters, Stream& interface)
{
  scpi_nCallInt32(parameters,1,&yStep, "move Y relative");
}
void xyStep(int32_t *pos)
{
  int32_t stepX = pos[0];
  int32_t stepY = pos[1];
  xStepper.runSpeedToPosition(xStepper.currentPosition()+stepX);
  yStepper.runSpeedToPosition(yStepper.currentPosition()+stepY);
  HD44780_SetCursor(0,3);
  snprintf(lcdline3, LCD_LENGTH+1, "R X%-6d Y%-6d", stepX, stepY);
  HD44780_PrintStr(lcdline3);
}



void scpi_xyStep(SCPI_C commands, SCPI_P parameters, Stream& interface)
{
  scpi_nCallInt32(parameters, 2, &xyStep, "move XY relative");
}

void xyAbs(int32_t *pos)
{
  int32_t posX = pos[0];
  int32_t posY = pos[1];
  xStepper.runSpeedToPosition(posX);
  yStepper.runSpeedToPosition(posY);
  HD44780_SetCursor(0,3);
  snprintf(lcdline3, LCD_LENGTH+1, "A X%-6d Y%-6d ", posX, posY);
  HD44780_PrintStr(lcdline3);
}
void scpi_xyAbs(SCPI_C commands, SCPI_P parameters, Stream& interface)
{
  scpi_nCallInt32(parameters, 2, &xyAbs, "move XY absolute");
}

void scpi_xZero(SCPI_C commands, SCPI_P parameters, Stream& interface)
{
  xStepper.setCurrentPosition(0);
}
void scpi_yZero(SCPI_C commands, SCPI_P parameters, Stream& interface)
{
  yStepper.setCurrentPosition(0);
}

void setCoilFreq(int32_t *freq)
{
  probeFrequency = freq[0];
  coilPWMFrequency = probeFrequency*2 * SINETABLESIZE*2;
  stopCoil();
  startCoil();
  HD44780_SetCursor(0,3);
  snprintf(lcdline3, LCD_LENGTH+1, "Coil %-6d            ", freq[0]);
  HD44780_PrintStr(lcdline3);
} 
void scpi_coilFreq(SCPI_C commands, SCPI_P parameters, Stream& interface)
{
  scpi_nCallInt32(parameters, 1, setCoilFreq, "Set coil freq");
}
void scpi_coilLift(SCPI_C commands, SCPI_P parameters, Stream& interface)
{
  liftCoil();
  HD44780_SetCursor(0,3);
  snprintf(lcdline3, LCD_LENGTH+1, "Coil lift            ");
  HD44780_PrintStr(lcdline3);
}
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
void loop() {
  Wire.setSCL(PB8);
  Wire.setSDA(PB9);
  Wire.setClock(400000);
  Wire.begin();
  
  delay(1000);
  HD44780_Init(4);
  HD44780_Clear();
  HD44780_NoDisplay();
  HD44780_SetCursor(0,0);
  HD44780_PrintStr("This machine");
  HD44780_SetCursor(0,1);
  HD44780_PrintStr("measures microns");
  HD44780_SetCursor(0,3);
  HD44780_PrintStr("UBC MECH 423");
  HD44780_Display();

  /* Register SCPI commands */
  parser.hash_magic_number = 113;        // You may need to adjust the hash magic number 
  parser.registerCommand("Join", &scpi_join);
  parser.registerCommand("pause", &scpi_pause);
  //parser.registerCommand("meas?", &scpi_meas);
  parser.SetCommandTreeBase("sys");
    parser.registerCommand(F("drate"),&scpi_uartDrate);
    parser.registerCommand(F("log"), &scpi_uartLog);  
    parser.registerCommand(F("debug"), &scpi_debug);
  parser.SetCommandTreeBase("xy");
    parser.registerCommand(F("abs"), &scpi_xyAbs);
    parser.registerCommand(F("ENable"),&scpi_steppersOn);
    parser.registerCommand(F("DISable"),&scpi_steppersOff);
    parser.registerCommand(F("step"),&scpi_xyStep);
    parser.registerCommand(F("SPeed"),&scpi_xySpeed);
  parser.SetCommandTreeBase(F("X"));                        // That's interesting. Not allowed to call this "x" lowercase
    parser.registerCommand(F("abs"), &scpi_xAbs);
    parser.registerCommand(F("step"), &scpi_xStep);
    parser.registerCommand(F("zero"), &scpi_xZero);
  parser.SetCommandTreeBase(F("Y"));
    parser.registerCommand(F("abs"), &scpi_yAbs);
    parser.registerCommand(F("step"), &scpi_yStep);
    parser.registerCommand(F("zero"), &scpi_yZero);
  parser.SetCommandTreeBase(F("ADC"));
    parser.registerCommand(F("drate"),&scpi_adcDrate);
    parser.registerCommand(F("RESet"),&scpi_adcReset);
    parser.registerCommand(F("offs"),&scpi_adcOffs);
    parser.registerCommand(F("cal"),&scpi_adcCal);
  parser.SetCommandTreeBase(F("Coil"));                   // Also interesting. If you put coil above adc it will erroneously do a coil drop even if you don't comand it
    parser.registerCommand(F("On"),&scpi_coilOn);
    parser.registerCommand(F("F"),&scpi_coilFreq);
    parser.registerCommand(F("Off"),&scpi_coilOff);
    parser.registerCommand(F("DROP"),&scpi_coilDrop);
    parser.registerCommand(F("LIFT"),&scpi_coilLift);
  Serial.begin(115200);
  Serial.flush();

  pinMode(PC13,OUTPUT);
  pinMode(PB13,OUTPUT);    // Temporary debug

  // Initial set up step generators in x and y
  xStepper.Timer->attachInterrupt(xStepper.PWMchannel, xStepISR);
  yStepper.Timer->attachInterrupt(yStepper.PWMchannel, yStepISR);
  xStepper.setSpeed(10000);
  yStepper.setSpeed(10000);

  mainTimer->setOverflow(1,HERTZ_FORMAT);
  mainTimer->setCaptureCompare(1, uartFreq, HERTZ_COMPARE_FORMAT);
  uartTicks = mainTimer->getCaptureCompare(1);                      // Calculate number of ticks to increment and store in uartTicks 
  mainTimer->setMode(1, TIMER_DISABLED);
  mainTimer->attachInterrupt(1, timer9_1ISR);
  mainTimer->setCaptureCompare(2, lcdFreq, HERTZ_COMPARE_FORMAT);
  lcdTicks = mainTimer->getCaptureCompare(2);
  mainTimer->setMode(2, TIMER_DISABLED);
  mainTimer->attachInterrupt(2, timer9_2ISR);
  mainTimer->refresh();
  mainTimer->resume();


  SPI.begin();                     
  adc.InitializeADC();
  resetADC();

  HD44780_NoDisplay();
  HD44780_Clear(); 
  HD44780_Display();

  HD44780_SetCursor(0,0);
  HD44780_PrintStr("Calibrating");
  // Initial offset calibration.
  int32_t sum = 0;
  uint16_t times = 128;
  for(int i = 0; i<times; i++)
  {
    sum += adc.readSingle();
  }
  adcRawCounts = sum/times; 
  counts_offset = adcRawCounts;

  HD44780_NoDisplay();
  HD44780_Clear(); 
  HD44780_SetCursor(0,0);
  HD44780_PrintStr("SCPI init OK");
  HD44780_SetCursor(0,1);
  HD44780_PrintStr("Self-tests passed");
  HD44780_Display();  
  delay(2000);
  
  // Test: set up and run coil
  sineMode = BRAKE;
  // startCoil();

  xStepper.enable();
  yStepper.enable();

  serial_ready();

  // Test: run steppers
  // tim11->setOverflow(100, HERTZ_FORMAT);
  // tim11->attachInterrupt(timer11_0ISR);
  // tim11->refresh();
  // tim11->resume();

  while(true)
  {
    char* message = parser.GetMessage(Serial,"\n");
    if(message != NULL)
    {
      // HD44780_SetCursor(0,3);
      // snprintf(lcdline3, LCD_LENGTH+1, message);
      // HD44780_PrintStr(lcdline3);                // Prints exact message to screen.
      parser.Execute(message, Serial);
      serial_ready();                               // Signal that buffer's been read, host can send more commands 
    }

    adcUpdateAll();

    if(lcdFlag)
    {
      updateLCD(1,1,1,0);
      lcdFlag = false;
    }
  }
}

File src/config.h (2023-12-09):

/**
 * SETTING PIN B0 AS INPUT INTERFERES WITH SPI
 * PA1 and PA0 interfere with each other because shared T2.
 * You need to put X and Y steppers on completely different timers.
*/

#ifndef CONFIG_H_
#define CONFIG_H_

//#define ADC_SYNC_AVAILABLE

#include <Arduino.h> // Type definitions 

#define SINETABLESIZE 90
/**
 * Sine lookup table with 8-bit values to 90 degrees
*/
const unsigned char sinA [] PROGMEM = 
{0, 4, 8, 13, 17, 22, 26, 31, 35, 39, 44, 48, 53, 57, 61, 65, 
70, 74, 78, 83, 87, 91, 95, 99, 103, 107, 111, 115, 119, 123, 
127, 131, 135, 138, 142, 146, 149, 153, 156, 160, 163, 167, 
170, 173, 177, 180, 183, 186, 189, 192, 195, 198, 200, 203, 
206, 208, 211, 213, 216, 218, 220, 223, 225, 227, 229, 231, 
232, 234, 236, 238, 239, 241, 242, 243, 245, 246, 247, 248, 
249, 250, 251, 251, 252, 253, 253, 254, 254, 254, 254, 254, 255};


/**
 * LCD ADC display setting
*/
enum dispSettings_T{
    COUNTS,
    VOLTS,
    CNEWTONS,
    MICRONS,
};

/** 
 * UART data tx/rx format enum
*/
enum logFormat_T{
    PACKET, 
    STRING
};

enum sineModes_T{
    BRAKE,              // PWM a sine wave using run/brake 
    COAST,              // PWM a sine wave using run/coast
    SQUARE              // PWM a square wave using run/brake
};


#define ADC_DRDY PA3
#define ADC_CS PA4
#if defined(ADC_SYNC_AVAILABLE)
    #define ADC_SYNC PA2
#else
    #define ADC_SYNC 0
#endif

#define stepPinx PB5
#define enPinx PB15
#define dirPinx PB2

#define stepPiny PA1
#define enPiny PA9
#define dirPiny PB1

#define coilInA PB6
#define coilInB PB7
#define coilPWMPinAux PA8


#endif

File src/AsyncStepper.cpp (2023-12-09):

#include <AsyncStepper.h>

/**
 * STM32 specific step-direction driver 
 * 
 * @param pwmPin Step pin. Must have a distinct hardware timer module from any other instance unless you want your steppers to run at the same time
 * @param dirPin Dir pin
 * @param enPin  En pin
 * @param Timer  Pointer to HardwareTimer object for PWM configuration (you could also modify this library to use the lower level TIMx instance)
 * @param PWMchannel PWM channel, must match step pin selection
 * @param maxSpeed   Speed limit in steps/second
*/
AsyncStepper::AsyncStepper(uint8_t pwmPin, uint8_t dirPin, uint8_t enPin, HardwareTimer* Timer_, uint32_t PWMchannel_, uint32_t maxSpeed){
    _pwmPin = pwmPin;
    _dirPin = dirPin;
    _enPin = enPin;
    _maxSpeed = maxSpeed;
    _currentPos = 0;
    _targetPos = 0;
    _speed = 1000;                  // arbitrary, some default value. 
    _direction = DIRECTION_STOP;
    Timer = Timer_;
    PWMchannel = PWMchannel_;

    pinMode(_pwmPin, OUTPUT);
    pinMode(_dirPin, OUTPUT);
    pinMode(_enPin, OUTPUT);
    
    Timer->setMode(PWMchannel, TIMER_OUTPUT_COMPARE_PWM1,_pwmPin);
    Timer->setOverflow(_speed,HERTZ_FORMAT);
    Timer->setCaptureCompare(PWMchannel, 20, PERCENT_COMPARE_FORMAT);
    Timer->refresh();
}

void AsyncStepper::enable()
{
    digitalWrite(_enPin, LOW);
}
void AsyncStepper::disable()
{
    digitalWrite(_enPin, HIGH);
}


// Run continuously at current speed.
// negative speed = negative rotation direction.
void AsyncStepper::runSpeed()
{
    _mode = 0;
    if(_speed >= 0) 
    {
        digitalWrite(_dirPin, _direction=DIRECTION_CW);
    }
    else 
    {
        digitalWrite(_dirPin, _direction=DIRECTION_CCW);
    }
    // STM32 hardware timer 
    Timer->resume();
}

// Move to target position at current speed. Target overrides speed. 
// if _speed is negative, but the target needs positive speed to reach,
// it will run positive speed.
void AsyncStepper::runSpeedToPosition(int32_t pos)
{
    _mode = 1;
    _targetPos = pos;
    if(pos-_currentPos > 0) 
    {
        digitalWrite(_dirPin, _direction=DIRECTION_CW);
    }
    else if(pos-_currentPos < 0)
    {
        digitalWrite(_dirPin, _direction=DIRECTION_CCW);
    }
    else{
        _direction = DIRECTION_STOP;
    }

    if(_currentPos != _targetPos)
    {
        // STM32 hardware timer 
        Timer->resume();
    }
    else{
        stop();
    }
}

void AsyncStepper::stop()
{
    _direction = DIRECTION_STOP;
    // STM32 hardware timer 
    Timer->pause();
}

void AsyncStepper::setMaxSpeed(int32_t maxSpeed_)
{
    _maxSpeed = abs(maxSpeed_);
}

void AsyncStepper::setSpeed(int32_t speed)
{
    if(speed == 0)
    {
        return;
    }
    if(abs(speed) > _maxSpeed )
    {
        _speed = (speed > 0 ? _maxSpeed : -_maxSpeed);
    }
    else
    {
        _speed = speed;
    }

    // STM32 hardware timer method
    //Timer->setPWM(PWMchannel, _pwmPin, _speed, 20);
    Timer->setMode(PWMchannel, TIMER_OUTPUT_COMPARE_PWM1,_pwmPin);
    Timer->setOverflow(_speed,HERTZ_FORMAT);
    Timer->setCaptureCompare(PWMchannel, 40, PERCENT_COMPARE_FORMAT);
    Timer->refresh();
}

void AsyncStepper::setCurrentPosition(int32_t pos)
{
    stop();
    _currentPos = pos;
}

void AsyncStepper::stepTimerISR()
{
    switch(_direction)
    {
        case DIRECTION_CCW:
            _currentPos--;
            break;
        case DIRECTION_CW:
            _currentPos++;
            break;
        case DIRECTION_STOP:
        default:
            break;
    }    
    
    if(_currentPos == _targetPos && _mode==1)
    {   
        // STM32 hardware timer 
        Timer->pause();
        _direction = DIRECTION_STOP;
    }
}

int32_t AsyncStepper::speed(){
    return _speed;
}

int32_t AsyncStepper::currentPosition(){
    return _currentPos;
}

int32_t AsyncStepper::targetPosition(){
    return _targetPos;
}

byte AsyncStepper::direction(){
    return _direction;
}

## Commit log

2023-12-17 Add kicad rough drafts
    [adc_board.kicad_pcb, adc_board.kicad_sch, controller.kicad_pcb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]
2023-12-18 Update Kicad files
    [adc_board.kicad_sch, controller.kicad_pcb, controller.kicad_sch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]
2025-08-22 Add CAD
    [00144585.SLDASM, 00144585_01.SLDPRT, 00144585_02.SLDPRT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]
